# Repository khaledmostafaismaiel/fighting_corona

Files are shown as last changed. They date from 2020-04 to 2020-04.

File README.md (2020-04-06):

# fighting_corona
___
___
this project is a mechanical ventilator which was inspiered from  which will help the people who have a problems in breathing
first of all i want to **thank** [Darren Lewis](https://www.youtube.com/watch?v=jutBw_xIwTw&t=2s)  and  [Datatrician](https://www.youtube.com/watch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) because my project was inspired from them and actually i use [Darren Lewis](https://www.youtube.com/watch?v=jutBw_xIwTw&t=2s) designes and made some changes on it.
___
>### MACHINE FEATURES
* user can control of the volume of oxygen per breath
* user can control the speed of breathing
* user can control the delay between the inhale and exhale
* user can control the delay between 2 breaths
* user can moitor the pressure and the temperature on the breathing all time on the LCD
___
>### MAIN SCENARIO
1. welcome message 
```
/*
   ###Fighting#####
   ####corona######
*/
```
2. init arm position to a certain position using min end stop
```
/*  
    #####please#####
    #####wait!######
*/
```  
  
3. get target number of steps which refer to the volume of oxygen per breath you can use potentiometer to choose the value and press ok when you done
```
/*  
    volume of oxygen
    ######10########
*/
```  

4. get delay between steps which refer to the speed of breathing you can use potentiometer to choose the value and press ok when you done
```
/*  
    #####speed######
    #######10#######
*/    
```  

5. get delay between inhale and exhale you can use potentiometer to choose the value and press ok when you done
```
/*  
    after inhale####
    wait###10#######
*/
```  

6. get delay between 2 breaths you can use potentiometer to choose the value and press ok when you done
```
/*  
    after breath####
    wait###10#######
*/
```  

7. now the doctor had set all prameters so the machine will mad 3 breaths to made the doctor sure from his setup
```
/*  
    #####wait!#####
    ###for test####
*/
```  

8. now we should connect the device with patient and every single ms we had the values of the pressure and the temperature of his breath
```
/*
    pressure=####10
    Temparature=#10
*/
```
___
> #### NOTES
1. you can use any 8mm material to cut it and build the device
2. its easy to build i think it will take no longer than 30min with electronic connections
3. in this days i havn't any electronic simulator so i couldn't build a circuit diagram but i will attach some photos for every single module   conection
4. in ved_des folder you will find the .dxf files and the assembly, i made them with SOLIDWORKS2013 which is very old so i think every one had the same version or higher can edit them if he want 
5. you can use list_of_material.txt file to buy or know the components prices
6. now i'm working on controlling the device using feadback from patient

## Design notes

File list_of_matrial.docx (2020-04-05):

Name | Quantity | Price/pice | Link
Arduino_uno | 1 | 145 | https://makerselectronics.com/product/arduino-uno
Sensor_pressure | 1 | 75 | https://makerselectronics.com/product/bmp-180
Nema_17 | 1 | 250 | https://makerselectronics.com/product/nema-17-stepper-motor-17hs4401s
Motor_driver | 1 | 40 | https://makerselectronics.com/product/a4988-stepper-motor-driver-2a
LCD_screen | 1 | 40 | https://makerselectronics.com/product/16x2-character-lcd
Micro_limit_switch | 2 | 3 | https://makerselectronics.com/product/micro-limit-switch-5a-125250v
Push_button | 1 | .5 | https://makerselectronics.com/product/mini-push-button-2-pin-6x6x4-3mm
Mini_Bread_board | 1 | 8 | https://makerselectronics.com/product/mini-breadboard-170-pin
Jumber_wires | 1 | 20 | https://makerselectronics.com/product/jumper-wires-for-bread-board-arduino-65pcs
Power_adapter | 1 | 30
Battery(optional) | 1 | 175 | https://makerselectronics.com/product/acid-battery-12v-1-2ahhr
potentiometer | 1 | 2.5 | https://electra.store/100k-ohm-potentiometer.html
knob | 1 | 3 | https://electra.store/potentiometer-knob-cap.html
Ambu | 1
| TOTAL | 620+ambu price

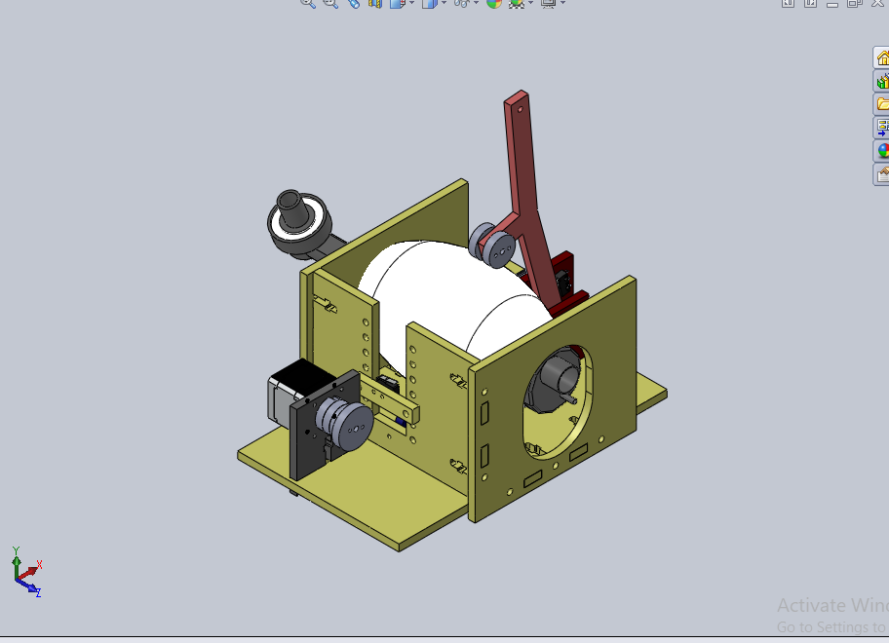
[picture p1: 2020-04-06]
Screenshot (71).png

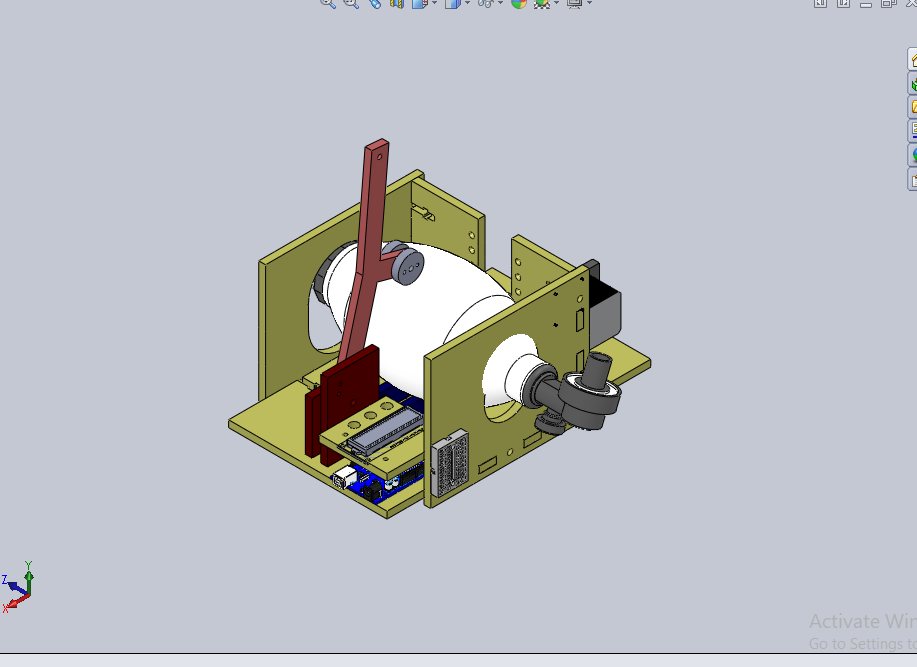
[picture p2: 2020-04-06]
Screenshot (72).png

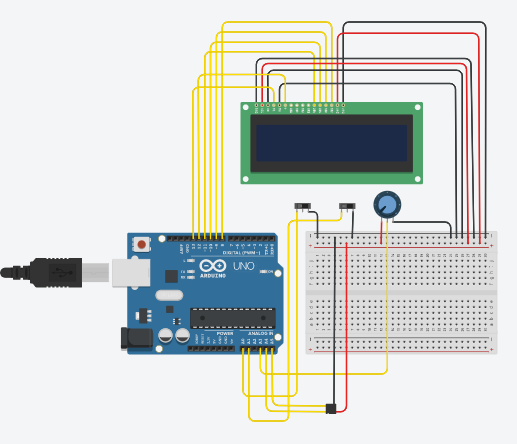
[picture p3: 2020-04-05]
circuit_diagram.png

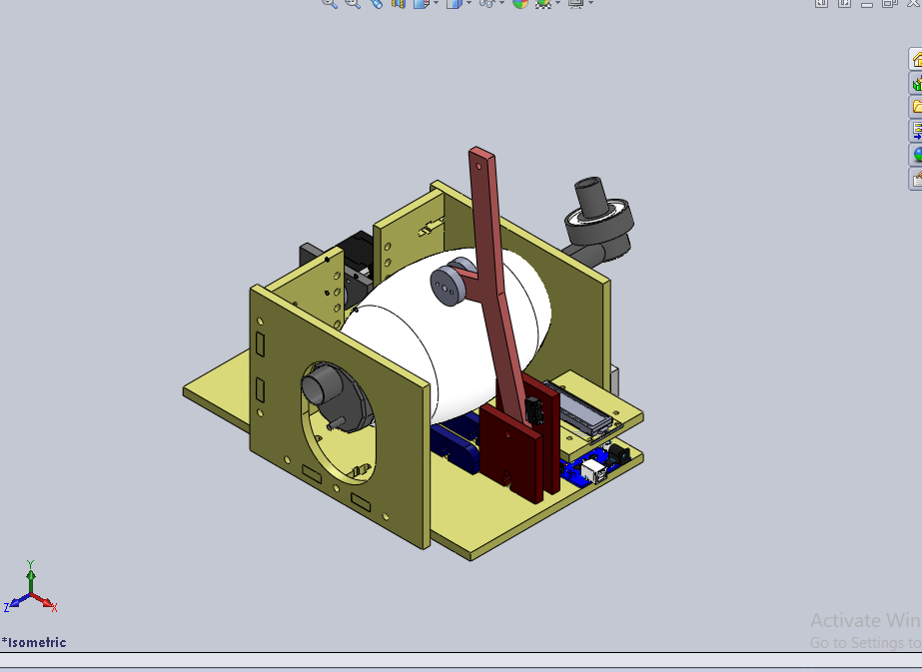
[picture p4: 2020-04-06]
Screenshot (70).png

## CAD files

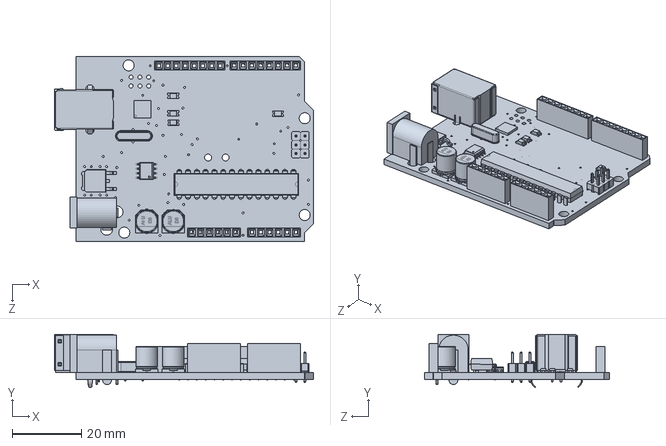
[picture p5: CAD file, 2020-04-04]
Ven_des/arduino_uno_for_assem.SLDASM.SLDPRT
74.7 x 15.4 x 53.3 mm

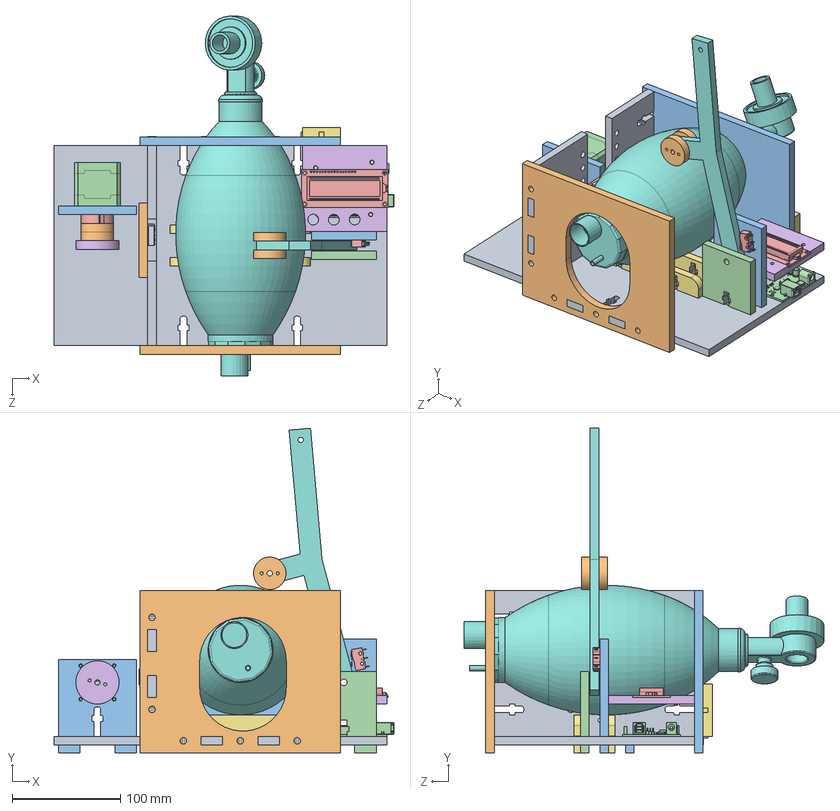
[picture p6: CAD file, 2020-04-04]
Ven_des/machine_aseembly.SLDASM
313.8 x 299.7 x 332.5 mm
bottom_side_for_assem
hub_wire_for_assem x 4
motor_mount_for_assem
nema_17_for_assem
hub_bolt_place_for_assem
hub_border_for_assem
ambu_support_for_assem x 2
arm_for_assem
back_side_for_assem
left_side_for_assem
right_side_for_assem
arduino_uno_for_assem.SLDASM
LCD_for_assem
lcd_support_plat_for_assem
bread_board_for_assem
ambu_for_assem
min_end_stop_for_assem
Min_end_stop_plat_for_assem
arm_R_support_for_assem
arm_L_support_for_assem
max_end_stop_for_assem

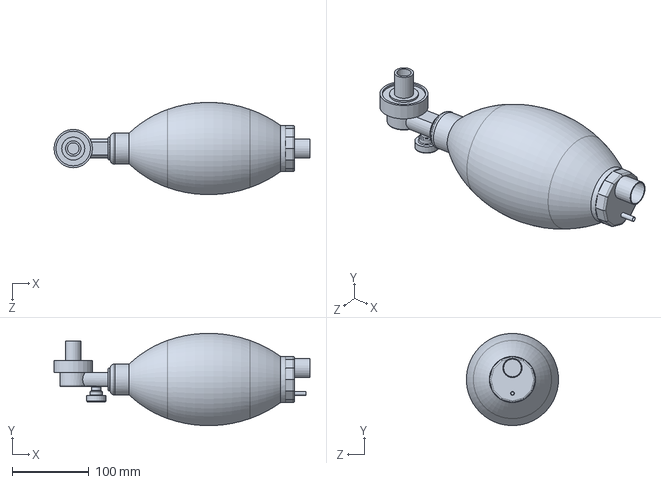
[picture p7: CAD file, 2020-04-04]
Ven_des/ambu_for_assem.SLDPRT
332.5 x 119.7 x 119.7 mm

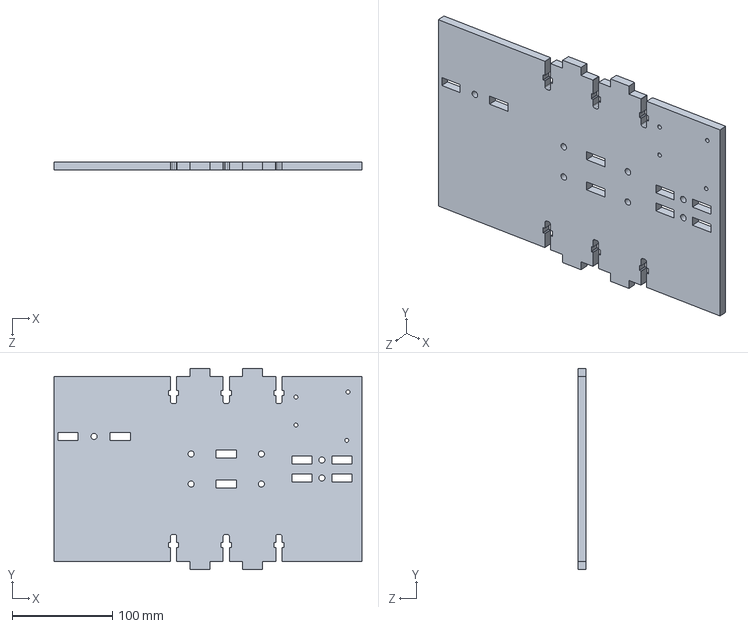
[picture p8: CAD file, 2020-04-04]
Ven_des/bottom_side_for_assem.SLDPRT
307.5 x 201.0 x 8.00 mm

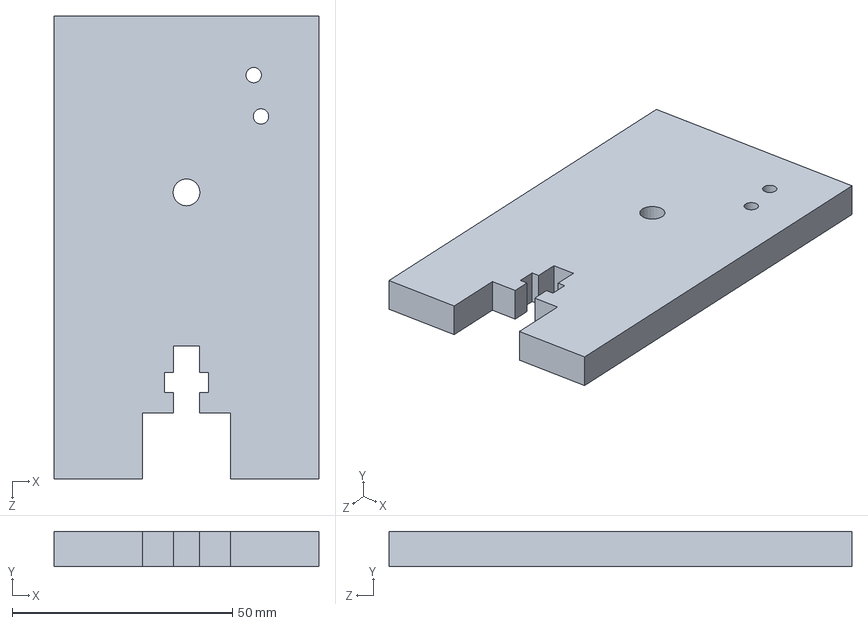
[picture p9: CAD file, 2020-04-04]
Ven_des/arm_R_support_for_assem.SLDPRT
60.0 x 8.00 x 105.0 mm

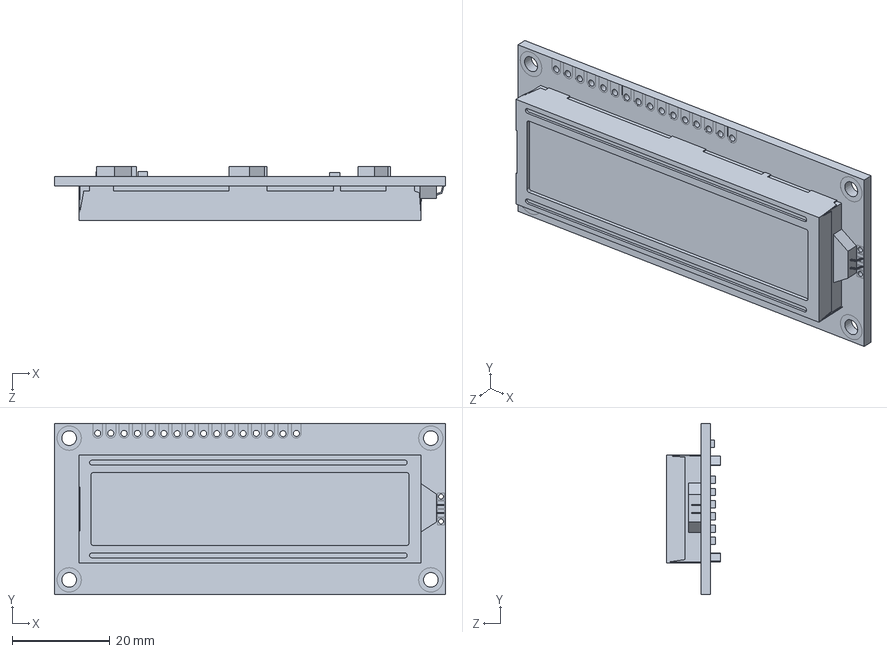
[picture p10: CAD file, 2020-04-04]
Ven_des/LCD_for_assem.SLDPRT
80.0 x 35.0 x 11.0 mm

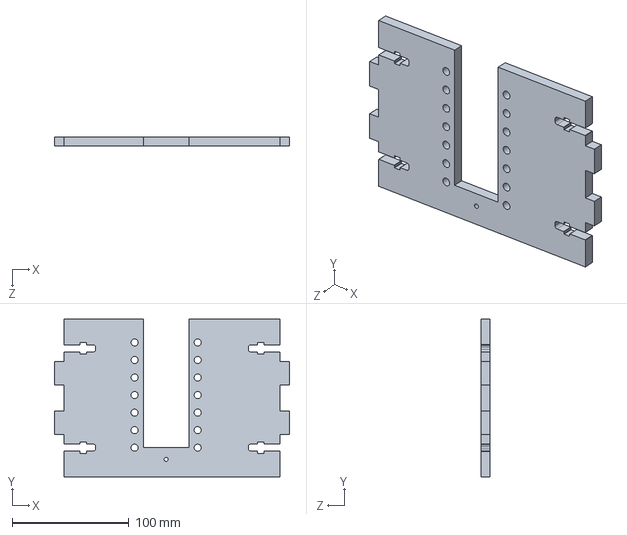
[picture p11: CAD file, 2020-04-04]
Ven_des/back_side_for_assem.SLDPRT
201.0 x 135.0 x 8.00 mm

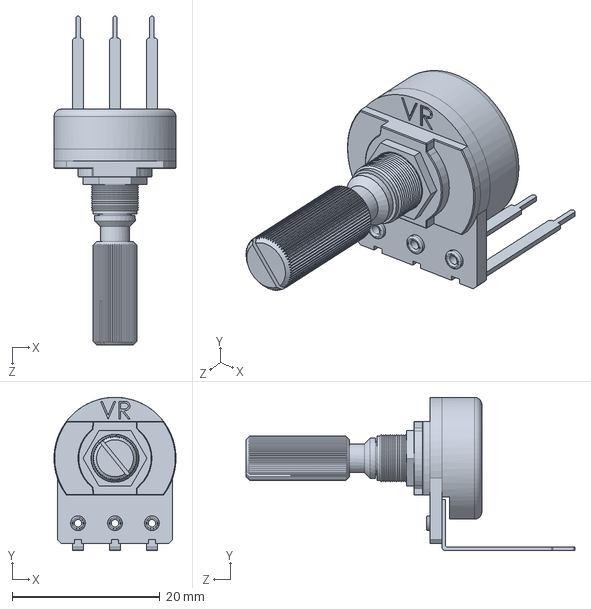
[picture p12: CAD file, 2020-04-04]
Ven_des/POTENTIOMETER_for_assem.SLDPRT
16.5 x 20.7 x 44.5 mm

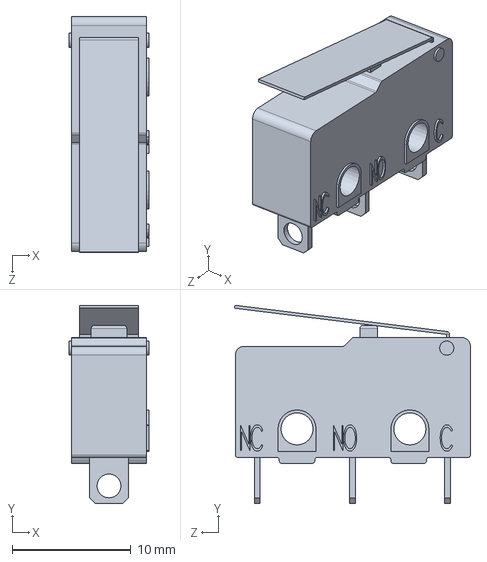
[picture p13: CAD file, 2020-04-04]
Ven_des/max_end_stop_for_assem.SLDPRT
6.75 x 16.7 x 19.9 mm

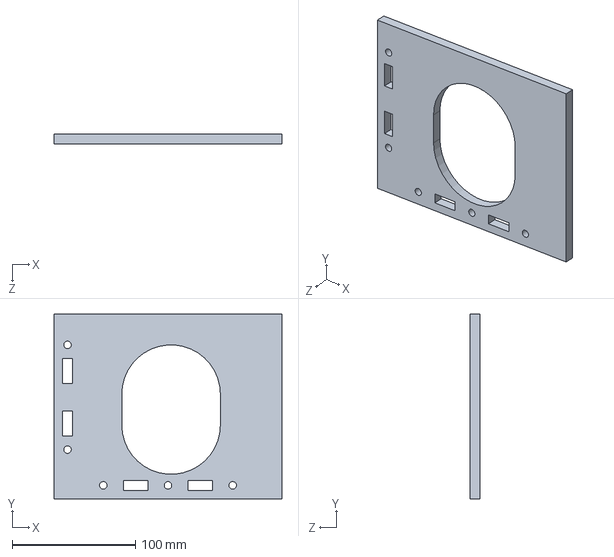
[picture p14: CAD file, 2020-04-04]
Ven_des/left_side_for_assem.SLDPRT
185.0 x 150.0 x 8.00 mm

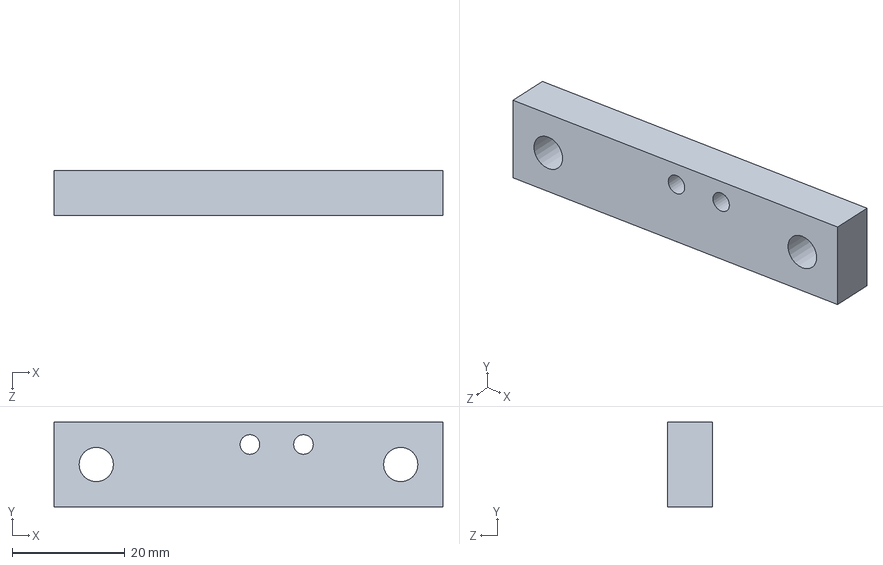
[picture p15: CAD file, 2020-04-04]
Ven_des/Min_end_stop_plat_for_assem.SLDPRT
69.0 x 15.0 x 8.00 mm

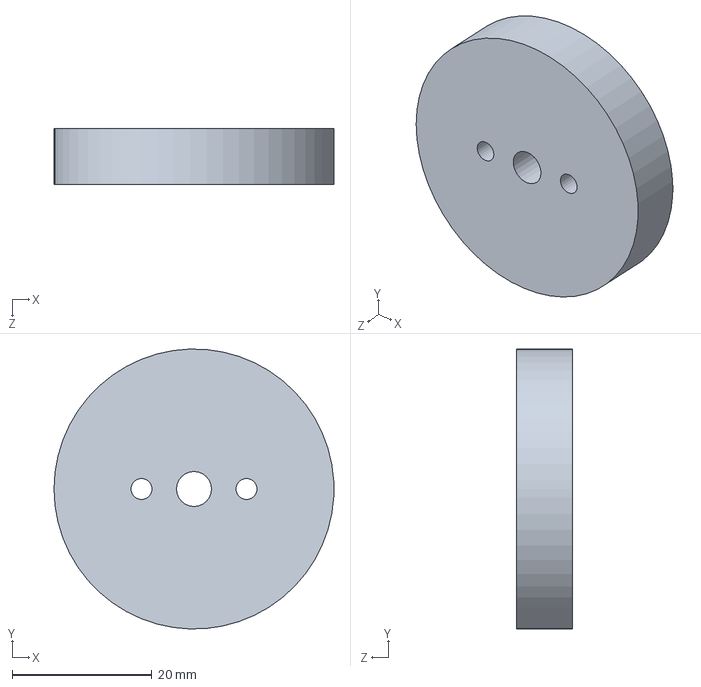
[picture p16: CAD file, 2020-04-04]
Ven_des/hub_border_for_assem.SLDPRT
40.0 x 40.0 x 8.00 mm

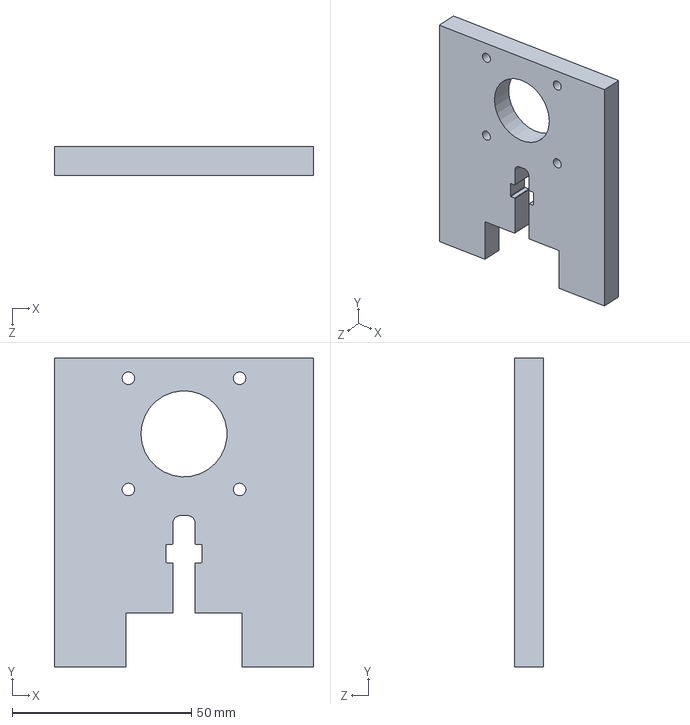
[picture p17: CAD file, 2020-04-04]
Ven_des/motor_mount_for_assem.SLDPRT
72.3 x 86.2 x 8.00 mm

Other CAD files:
Ven_des/arm_L_support.SLDPRT
Ven_des/back_side.SLDPRT
Ven_des/right_side.SLDPRT
Ven_des/lcd_support_plat.SLDPRT
Ven_des/left_side.SLDPRT
Ven_des/Min_end_stop_plat.DXF
Ven_des/Min_end_stop_plat.SLDPRT
Ven_des/ambu_support.DXF
Ven_des/ambu_support.SLDPRT
Ven_des/ambu_support_for_assem.SLDPRT
Ven_des/arm.DXF
Ven_des/arm.SLDPRT
Ven_des/arm_L_support.DXF
Ven_des/arm_L_support_for_assem.SLDPRT
Ven_des/arm_R_support.DXF
Ven_des/arm_R_support.SLDPRT
Ven_des/arm__L_support.DXF
Ven_des/arm__R_support.DXF
Ven_des/arm_for_assem.SLDPRT
Ven_des/back_side.DXF
Ven_des/bottom_side.DXF
Ven_des/bottom_side.SLDPRT
Ven_des/bread_board_for_assem.SLDPRT
Ven_des/hub_bolt_place.DXF
Ven_des/hub_bolt_place.SLDPRT
Ven_des/hub_bolt_place_for_assem.SLDPRT
Ven_des/hub_border.DXF
Ven_des/hub_border.SLDPRT
Ven_des/hub_wire.DXF
Ven_des/hub_wire.SLDPRT
Ven_des/hub_wire_for_assem.SLDPRT
Ven_des/lcd_support_plat.DXF
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

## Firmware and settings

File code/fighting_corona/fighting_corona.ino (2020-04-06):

#include <Adafruit_BMP085.h>
#include <Wire.h>
#include <LiquidCrystal.h>



//preproccesor section

#define MIN_DELAY_BETWEEN_INHALE_AND_EXHALE 100
#define MAX_DELAY_BETWEEN_INHALE_AND_EXHALE 500

#define MIN_DELAY_BETWEEN_2_BREATHS 100
#define MAX_DELAY_BETWEEN_2_BREATHS 500

#define MIN_DELAY_BETWEEN_STEPS 100
#define MAX_DELAY_BETWEEN_STEPS 100

#define MIN_DELAY_BETWEEN_INHALE_AND_EXHALE 100
#define MAX_DELAY_BETWEEN_INHALE_AND_EXHALE 500

#define STEPPER_MOTOR_STEP_PIN 2
#define STEPPER_MOTOR_DIR_PIN 3

#define LED_PIN 4
#define BUZZER_PIN 5

#define MIN_END_STOP_PIN A0
#define MAX_END_STOP_PIN A1

#define select_BUTTON_PIN A2

#define POTENTIOMETER_PIN A3

#define NUMBER_OF_TESTS 3



#define RS_PIN 13
#define EN_PIN 12
#define D4_PIN 11
#define D5_PIN 10
#define D6_PIN 9
#define D7_PIN 8
#define NUMBER_OF_ROWS 2
#define NUMBER_OF_COLUMNS 16



//methods prototypes

void stepper_move(int dir_pin , int step_pin , char dir , double delay_time);
void init_arm_position(void);
int get_target_number_of_steps();
int get_delay_between_steps(int target_steps);
int get_delay_between_Inhalation_exhalation(int target_steps, int steps_delay);
int get_delay_between_2_breaths(int target_steps, int steps_delay, int delay_after_inhale_exhale);
void test_movement(int target_steps, int steps_delay, int inhale_delay, int breath_breath_delay);
void welcome_message();

//global variable section

LiquidCrystal lcd_screen(RS_PIN, EN_PIN, D4_PIN, D5_PIN, D6_PIN, D7_PIN); //creating lcd_screen variable RS,EN,D4,D5,D6,D7

Adafruit_BMP085 bmp;  //creating sensor pressure variable

int target_number_of_steps = 0;
int delay_between_steps = 0 ;
int delay_between_Inhalation_exhalation = 0;
int delay_between_2_breaths = 0 ;
int avrage_pressure = 0 ;
int avrage_temp = 0 ;



void setup() {

  lcd_screen.begin(NUMBER_OF_COLUMNS, NUMBER_OF_ROWS);  //init lcd_screen

  bmp.begin(); //init bmp pressure sensor

  pinMode(STEPPER_MOTOR_STEP_PIN , OUTPUT); //init step_pin for stepper motor
  pinMode(STEPPER_MOTOR_DIR_PIN , OUTPUT); //init dir_pin for stepper motor

  pinMode(LED_PIN , OUTPUT);  //init for led
  pinMode(BUZZER_PIN , OUTPUT); //init for buzzer

  pinMode(MIN_END_STOP_PIN , INPUT); //init for MIN_END_STOP_PIN
  pinMode(MAX_END_STOP_PIN , INPUT); //init for MAX_END_STOP_PIN
  pinMode(select_BUTTON_PIN , INPUT); //init for select_BUTTON_PIN
  pinMode(POTENTIOMETER_PIN , INPUT); //init for POTENTIOMETER_PIN


  welcome_message();
  
  init_arm_position();  //init arm position

  delay(500); //to prevent conflict between potentiometer readings

  target_number_of_steps = get_target_number_of_steps();  //get target number of steps to detrmine the volume of breath

  delay(500); //to prevent conflict between potentiometer readings

  init_arm_position();  //init arm position

  delay(500); //to prevent conflict between potentiometer readings

  delay_between_steps = get_delay_between_steps(target_number_of_steps);  //get target delay between steps

  delay(500); //to prevent conflict between potentiometer readings

  init_arm_position();  //init arm position

  delay(500); //to prevent conflict between potentiometer readings

  delay_between_Inhalation_exhalation = get_delay_between_Inhalation_exhalation(target_number_of_steps, delay_between_steps);

  delay(500); //to prevent conflict between potentiometer readings

  init_arm_position();  //init arm position

  delay(500); //to prevent conflict between potentiometer readings

  get_delay_between_2_breaths(target_number_of_steps, delay_between_steps, delay_between_Inhalation_exhalation);

  delay(500); //to prevent conflict between potentiometer readings

  init_arm_position();  //init arm position

  delay(500); //to prevent conflict between potentiometer readings

  test_movement(target_number_of_steps, delay_between_steps, delay_between_Inhalation_exhalation, delay_between_2_breaths); //test the user values before patiant 3 times

  delay(500); //to prevent conflict between potentiometer readings

  init_arm_position();  //init arm position



}



void loop()
{


  if (digitalRead(select_BUTTON_PIN) != LOW) {

    //start syncronization    
  }

  for(int i = 0 ; i < target_number_of_steps ; ++i){
  
    stepper_move(STEPPER_MOTOR_DIR_PIN, STEPPER_MOTOR_STEP_PIN, 'D', delay_between_steps);

    get_pressure();
      
    get_temp();

  }


  
  delay(delay_between_Inhalation_exhalation);




  for(int i = 0 ; i < target_number_of_steps ; ++i){
  
    stepper_move(STEPPER_MOTOR_DIR_PIN, STEPPER_MOTOR_STEP_PIN, 'U', delay_between_steps);

      lcd_screen.setCursor(0, 0);//set the cursor to column 0, line1

      get_pressure();
      
      lcd_screen.setCursor(0, 1);

      get_temp();
      
  }



  
  delay(get_delay_between_2_breaths);
  


}





/*
*Function: stepper_move
*
*used to move stepper motor up and down which will control the arm
*
*return void
*/
void stepper_move(int dir_pin , int step_pin , char dir , double delay_time) {


  switch (dir) {

    case 'U':  digitalWrite(dir_pin, HIGH);

      digitalWrite(step_pin, HIGH);
      delayMicroseconds(delay_time);
      digitalWrite(step_pin, LOW);
      delayMicroseconds(delay_time);

      break;

    case 'D':  digitalWrite(dir_pin, LOW);

      digitalWrite(step_pin, HIGH);
      delayMicroseconds(delay_time);
      digitalWrite(step_pin, LOW);
      delayMicroseconds(delay_time);

      break;

    default: ;
      break;

  }
}




/*
*Function: init_arm_position
*
*used to init the arm to a certain position which will only accomplish when arm hit the min_end_stop 
*
*return void
*/
void init_arm_position() {


  /*
    #####please#####
    #####wait!######
  */
  lcd_screen.clear();//clear display
  lcd_screen.setCursor(5, 0); 
  lcd_screen.print("please");
  lcd_screen.setCursor(5, 1);
  lcd_screen.print("wait!");

  while (MIN_END_STOP_PIN == LOW) {
    stepper_move(STEPPER_MOTOR_DIR_PIN, STEPPER_MOTOR_STEP_PIN, 'U', 500);

  }
  
    lcd_screen.clear();//clear display

}



/*
*Function: get_target_number_of_steps
*
*used to detrmine the number of steps which will make the desired volume of oxygen per breath from ambu 
*
*return current_postion
*/
int get_target_number_of_steps() {


  /*
    volume of oxygen
    ######10########
  */
  lcd_screen.clear();//clear display  
  lcd_screen.setCursor(0, 0); 
  lcd_screen.print("volume of oxygen");


  int current_postion = 0 ;
  int current_potentiometer_value = 0;
  int last_potentiometer_value = 0;

  while (digitalRead(select_BUTTON_PIN) == LOW) {
    
    current_potentiometer_value = analogRead(POTENTIOMETER_PIN);  
    
    lcd_screen.setCursor(6, 1);
    lcd_screen.print(String(current_potentiometer_value));
    
    if (current_potentiometer_value > last_potentiometer_value ) {
      if (MAX_END_STOP_PIN == LOW) {
        stepper_move(STEPPER_MOTOR_DIR_PIN, STEPPER_MOTOR_STEP_PIN, 'D', 500);
        ++current_postion;
      }
    } else if (current_potentiometer_value < last_potentiometer_value) {
      if (MIN_END_STOP_PIN == LOW) {
        stepper_move(STEPPER_MOTOR_DIR_PIN, STEPPER_MOTOR_STEP_PIN, 'U', 500);
        --current_postion;
      }
    } else {

    }
    last_potentiometer_value = current_potentiometer_value ;
  }


  lcd_screen.clear();//clear display

  return current_postion ;
}




/*
*Function: get_delay_between_steps
*
*used to detrmine the delay_between_steps which will control the speed of stepper motor which will influnce the speed of inhale and exhale
*
*return target_delay
*/
int get_delay_between_steps(int target_steps) {

  /*
    #####speed######
    #######10#######
  */
  lcd_screen.clear();//clear display
  lcd_screen.setCursor(5, 0); 
  lcd_screen.print("speed");

  
  
  int exit_condition = 0 ;
  int target_delay = 0 ;

  while (exit_condition == 0) {

    for (int i = 0 ; (i < target_steps) && (MAX_END_STOP_PIN == LOW); ++i) {

      target_delay = analogRead(POTENTIOMETER_PIN);
      target_delay = map(target_delay, 0, 1023, MIN_DELAY_BETWEEN_STEPS, MAX_DELAY_BETWEEN_STEPS); //maping the potentiometer value with MIN_DELAY_BETWEEN_STEPS,MAX_DELAY_BETWEEN_STEPS
      
      lcd_screen.setCursor(6, 1);
      lcd_screen.print(String(target_delay));
      
      stepper_move(STEPPER_MOTOR_DIR_PIN, STEPPER_MOTOR_STEP_PIN, 'D', target_delay);

      if (digitalRead(select_BUTTON_PIN) != LOW) {
        exit_condition = 1 ;  //to break from while loop
        break;
      }

    }

    delay(200);

    init_arm_position();  //init arm position

  }

  lcd_screen.clear();//clear display

  return target_delay ;
}



/*
*Function: get_delay_between_Inhalation_exhalation
*
*used to detrmine the delay_between_Inhalation_exhalation
*
*return target_delay
*/
int get_delay_between_Inhalation_exhalation(int target_steps, int steps_delay) {


  /*
    after inhale####
    wait###10#######
  */
  lcd_screen.clear();//clear display
  lcd_screen.setCursor(5, 0); 
  lcd_screen.print("after inhale");

  
  int target_delay = 0 ;
  int exit_condition = 0 ;

  while (exit_condition == 0) {

    for (int i = 0 ; (i < target_steps) ; ++i) {

      target_delay = analogRead(POTENTIOMETER_PIN);
      target_delay = map(target_delay, 0, 1023, MIN_DELAY_BETWEEN_INHALE_AND_EXHALE, MAX_DELAY_BETWEEN_INHALE_AND_EXHALE); //maping the potentiometer value with MIN_DELAY_BETWEEN_INHALE_AND_EXHALE,MAX_DELAY_BETWEEN_INHALE_AND_EXHALE

      lcd_screen.setCursor(0, 1);
      lcd_screen.print(String("wait   ") + String(target_delay));
      
      stepper_move(STEPPER_MOTOR_DIR_PIN, STEPPER_MOTOR_STEP_PIN, 'D', steps_delay);

      if (digitalRead(select_BUTTON_PIN) != LOW) {
        exit_condition = 1 ;  //to break from while loop
        break;
      }

    }

    delay(target_delay);

    if(exit_condition == 0){
      for (int i = 0 ; i < target_steps ; ++i) {
  
        target_delay = analogRead(POTENTIOMETER_PIN);
        target_delay = map(target_delay, 0, 1023, MIN_DELAY_BETWEEN_INHALE_AND_EXHALE, MAX_DELAY_BETWEEN_INHALE_AND_EXHALE); //maping the potentiometer value with MIN_DELAY_BETWEEN_INHALE_AND_EXHALE,MAX_DELAY_BETWEEN_INHALE_AND_EXHALE

        lcd_screen.setCursor(0, 1);
        lcd_screen.print(String("wait   ") + String(target_delay));
        
        stepper_move(STEPPER_MOTOR_DIR_PIN, STEPPER_MOTOR_STEP_PIN, 'U', steps_delay);
  
        if (digitalRead(select_BUTTON_PIN) != LOW) {
          exit_condition = 1 ;  //to break from while loop
          break;
  
        }
      }
    }
  }

  lcd_screen.clear();//clear display

  return target_delay ;
}


/*
*Function: get_delay_between_2_breaths
*
*used to detrmine the delay_between_2_breaths
*
*return target_delay
*/
int get_delay_between_2_breaths(int target_steps, int steps_delay, int inhale_delay) {

  /*
    after breath####
    wait###10#######
  */
  lcd_screen.clear();//clear display
  lcd_screen.setCursor(5, 0); 
  lcd_screen.print("after breath");

  
  int target_delay = 0 ;
  int exit_condition = 0 ;
  while (exit_condition == 0) {

    for (int i = 0 ; i < target_steps ; ++i) {

      target_delay = analogRead(POTENTIOMETER_PIN);
      target_delay = map(target_delay, 0, 1023, MIN_DELAY_BETWEEN_2_BREATHS, MAX_DELAY_BETWEEN_2_BREATHS); //maping the potentiometer value with MIN_DELAY_BETWEEN_2_BREATHS,MAX_DELAY_BETWEEN_2_BREATHS

      lcd_screen.setCursor(0, 1);
      lcd_screen.print(String("wait   ") + String(target_delay));
        
      stepper_move(STEPPER_MOTOR_DIR_PIN, STEPPER_MOTOR_STEP_PIN, 'D', steps_delay);

      if(digitalRead(select_BUTTON_PIN) == LOW){
        exit_condition = 1 ;  //to break from while loop
        break ;
      }
    
    }


    if(exit_condition == 0 ){
      delay(inhale_delay);
    }

    
    if(exit_condition == 0){
      
      for (int i = 0 ; i < target_steps ; ++i) {
  
        target_delay = analogRead(POTENTIOMETER_PIN);
        target_delay = map(target_delay, 0, 1023, MIN_DELAY_BETWEEN_2_BREATHS, MAX_DELAY_BETWEEN_2_BREATHS); //maping the potentiometer value with MIN_DELAY_BETWEEN_2_BREATHS,MAX_DELAY_BETWEEN_2_BREATHS

        lcd_screen.setCursor(0, 1);
        lcd_screen.print(String("wait   ") + String(target_delay));
          
        stepper_move(STEPPER_MOTOR_DIR_PIN, STEPPER_MOTOR_STEP_PIN, 'U', steps_delay);
      }
    }

    if(exit_condition == 0 ){
      delay(target_delay);
    }

  }


  lcd_screen.clear();//clear display

  return target_delay ;

}




/*
*Function: test_movement
*
*used to test the user choises if its suitable for the patient or not 
*
*return void
*/
void test_movement(int target_steps, int steps_delay, int inhale_delay, int breath_breath_delay) {

  /*
    #####wait!#####
    ###for test####
  */

  lcd_screen.clear();//clear display
  lcd_screen.setCursor(5, 0); 
  lcd_screen.print("wait!");
  lcd_screen.setCursor(3, 1);
  lcd_screen.print("for test");
 
  
  for (int i = 0 ; i < NUMBER_OF_TESTS ; ++i) {

    for (int j = 0 ; j < target_steps ; ++j) {
      stepper_move(STEPPER_MOTOR_DIR_PIN, STEPPER_MOTOR_STEP_PIN, 'D', steps_delay);
    }

    delay(inhale_delay);

    for (int k = 0 ; k < target_steps ; ++k) {
      stepper_move(STEPPER_MOTOR_DIR_PIN, STEPPER_MOTOR_STEP_PIN, 'U', steps_delay);
    }

    delay(breath_breath_delay);


  }

  lcd_screen.clear();//clear display

}

/*
*Function: get_pressure
*
*used to get the pressure of the patient
*
*return pressure
*/
int get_pressure(){

  /*
    pressure=####10
    ###############
  */

  
  char PRESSURESHOW[4]; // initializing a character of size 4 for showing the result
  lcd_screen.clear();//clear display
  lcd_screen.setCursor(0, 0);//set the cursor to column 0, line1
  lcd_screen.print("Pressure= ");
  
  String PRESSUREVALUE = String(bmp.readPressure());
  PRESSUREVALUE.toCharArray(PRESSURESHOW, 4);
  
  lcd_screen.print(PRESSURESHOW);
  lcd_screen.print("hPa ");
   
  return bmp.readPressure() ;
}


/*
*Function: get_pressure
*
*used to get the temp of the patient
*
*return temp
*/
int get_temp(){


  /*
    ###############
    Temparature=#10
  */
  char TEMPARATURESHOW[4];  // initializing a character of size 4 for showing the temparature result

  lcd_screen.setCursor(0, 1);//set the cursor to column 0, line1

  lcd_screen.print("Temparature=");// print name
  
  String TEMPARATUREVALUE = String(bmp.readTemperature());
  TEMPARATUREVALUE.toCharArray(TEMPARATURESHOW, 4);

  lcd_screen.print(TEMPARATURESHOW);
  lcd_screen.print("C ");
  
 return bmp.readTemperature() ;
}


void welcome_message(){
  /*
    ###Fighting#####
    ####corona######
  */

  lcd_screen.clear();//clear display
  lcd_screen.setCursor(2, 0); 
  lcd_screen.print("Fighting");
  lcd_screen.setCursor(3, 1);
  lcd_screen.print("Corona");
  delay (2000);
  lcd_screen.clear();//clear display

}

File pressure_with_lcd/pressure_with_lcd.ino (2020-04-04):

#include <Adafruit_BMP085.h>
#include <Wire.h>
#include <LiquidCrystal.h>



            //preproccesor section
            
#define MIN_NUM_OF_BREATHS 10
#define MAX_NUM_OF_BREATHS 20

#define MIN_VOL_PER_BREATH 1
#define MAX_VOL_PER_BREATH 5

#define STEPPER_MOTOR_STEP_PIN 2 
#define STEPPER_MOTOR_DIR_PIN 3 

#define LED_PIN 4
#define BUZZER_PIN 5

#define MIN_END_STOP_PIN A0
#define MAX_END_STOP_PIN A1

#define select_BUTTON_PIN A2

#define POTENTIOMETER_PIN A3


#define RS_PIN 13
#define EN_PIN 12
#define D4_PIN 11
#define D5_PIN 10
#define D6_PIN 9
#define D7_PIN 8
#define NUMBER_OF_ROWS 2
#define NUMBER_OF_COLUMNS 16



            //global variable section
            
LiquidCrystal lcd_screen(RS_PIN, EN_PIN, D4_PIN, D5_PIN, D6_PIN, D7_PIN); //creating lcd_screen variable RS,EN,D4,D5,D6,D7

Adafruit_BMP085 bmp;  //creating sensor pressure variable


            //methods prototypes
            
void stepper_move(int dir_pin , int step_pin , char dir ,double delay_time);

int number_of_breaths = 0 ;
int volume_of_oxygen = 0 ;
char PRESSURESHOW[4]; // initializing a character of size 4 for showing the result
char TEMPARATURESHOW[4];  // initializing a character of size 4 for showing the temparature result
double delay_between_steps = 0 ;
double delay_between_Inhalation_exhalation = 0;

void setup() {
  
  lcd_screen.begin(NUMBER_OF_COLUMNS, NUMBER_OF_ROWS);  //init lcd_screen


  //init bmp pressure sensor
  if (!bmp.begin())
  {
    Serial.println("ERROR IN COMMUNICATION BETWEEN BMP_SENSOR AND ARDUINO_BOARD");///if there is an error in communication
    while (1) {
      //if init didnt work correctly flash led and buzzer will turn on and off for ever
      digitalWrite(LED_PIN, HIGH);   // turn the LED on (HIGH is the voltage level)
      digitalWrite(BUZZER_PIN, HIGH);
      delay(500);                       // wait for a second
      digitalWrite(LED_PIN, LOW);    // turn the LED off by making the voltage LOW
      digitalWrite(BUZZER_PIN, LOW);
      delay(500);   
    }
  }
  
  pinMode(STEPPER_MOTOR_STEP_PIN , OUTPUT); //init step_pin for stepper motor
  pinMode(STEPPER_MOTOR_DIR_PIN , OUTPUT); //init dir_pin for stepper motor

  pinMode(LED_PIN , OUTPUT);  //init for led
  pinMode(BUZZER_PIN , OUTPUT); //init for buzzer

  pinMode(MIN_END_STOP_PIN , INPUT); //init for MIN_END_STOP_PIN
  pinMode(MAX_END_STOP_PIN , INPUT); //init for MAX_END_STOP_PIN
  pinMode(select_BUTTON_PIN , INPUT); //init for select_BUTTON_PIN
  pinMode(POTENTIOMETER_PIN , INPUT); //init for POTENTIOMETER_PIN


  //ask user about number of breaths per minute
  while(digitalRead(select_BUTTON_PIN) == LOW){
    number_of_breaths = analogRead(POTENTIOMETER_PIN);
    number_of_breaths = map(potentiometer_value, 0, 1023, MIN_NUM_OF_BREATHS,MAX_NUM_OF_BREATHS); //maping the potentiometer value with MIN_NUM_OF_BREATHS,MAX_NUM_OF_BREATHS
    
    lcd.setCursor(0, 0); // top left
    lcd_screen.print("number of breaths\t",number_of_breaths);
    delay (100);
    lcd_screen.clear();//clear display
  }
  
  delay(500); // to prevnt interruption between the last select_BUTTON_PIN status and the next select_BUTTON_PIN status

  //ask user about volume of oxygen per breath
  while(digitalRead(select_BUTTON_PIN) == LOW){
    volume_of_oxygen = analogRead(POTENTIOMETER_PIN);
    volume_of_oxygen = map(potentiometer_value, 0, 1023, MIN_VOL_PER_BREATH,MAX_VOL_PER_BREATH);  //maping the potentiometer value with MIN_VOL_PER_BREATH,MAX_VOL_PER_BREATH
      
    lcd.setCursor(0, 0); // top left
    lcd_screen.print("volume of oxygen\t",volume_of_oxygen);
    delay (100);
    lcd_screen.clear();//clear display
  }



/*
now we should use number_of_breaths and volume_of_oxygen to help us to find the values of delay_between_steps and delay_between_Inhalation_exhalation
*/


}




void loop()
{

/*
احنا فاللوب بتاع مش محتاجين حاجه غير ان الماتور يعمل الشهيق والزفير ويستنى بينهم وقت معين ويفضل بيعرض قيمه الضغط ودرجه الحراره على الشاشه
*/



/*
شهيق

وبيعرض الضغط ودرجه الحراره على الشاشه

لو حصل والمريض كح الجهاز هيوقف ويشتغل بعد م يبطل

*/



/*

delay

وبيعرض الضغط ودرجه الحراره على الشاشه

*/



/*
زفير

وبيعرض الضغط ودرجه الحراره على الشاشه

لو حصل والمريض كح الجهاز هيوقف ويشتغل بعد م يبطل

*/


/*

delay

وبيعرض الضغط ودرجه الحراره على الشاشه

*/



}






void stepper_move(int dir_pin , int step_pin , char dir ,double delay_time){


  switch(dir_pin){

    case 'U':  digitalWrite(dir_pin,HIGH);
    
              digitalWrite(step_pin,HIGH);
              delayMicroseconds(delay_time);
              digitalWrite(step_pin,LOW);
              delayMicroseconds(delay_time);
              
              break;

    case 'D':  digitalWrite(dir_pin,LOW);
            
              digitalWrite(step_pin,HIGH);
              digitalWrite(step_pin,LOW);
              delayMicroseconds(delay_time);

              break; 
               
    default: break;
  
  }


}
